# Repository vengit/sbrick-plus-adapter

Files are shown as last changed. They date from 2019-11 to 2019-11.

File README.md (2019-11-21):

# SBrick Plus adapters

This is a repository of code and documentation regarding the SBrick Plus
adapter project.

The material published here is available under the Creative Commons 4.0
International + Noncommercial + NoDerivatives license.

The following material is available:

## Documentation (directory "documentations")

Documentation covers some introduction, description of the physical parts and
some assembly instructions.

## Gerber files (directory "gerbers")

Gerber files can be used to manufacture the printed circuit boards (PCBs).

There are separate PCBs for sensor and motor adapters.

## Firmware code (directory "sbrick-adapter-firmware")

Sensor adapters contain a microcontroller. This microcontroller must be
programmed before use. The source code of the program is provided in the
directory called "sbrick-adapter-firmware".

## Schematic for the electronics (directory "schematic")

Contains schematics for the motor and sensor adapters. The schematic files
can be opened with [gEDA schematic editor](http://www.geda-project.org/).
Also contains bill of materials.

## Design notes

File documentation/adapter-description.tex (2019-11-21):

\documentclass[a4paper,12pt]{article}

\usepackage[utf8]{inputenc}
\usepackage[T1]{fontenc}
\usepackage[english]{babel}
\usepackage{times}
\usepackage{graphicx}

\setlength{\parindent}{0pt}
\setlength{\parskip}{2ex}

\title{SBrick Plus adapter types, parts, assembly steps}

\author{VENGIT Ltd.}

\begin{document}

\maketitle

\pagebreak

\section{Relevant LEGO product lines}

This document contains references to various LEGO product lines. In the
following pages there are descriptions and images of these product lines.

\subsection{LEGO Technic}

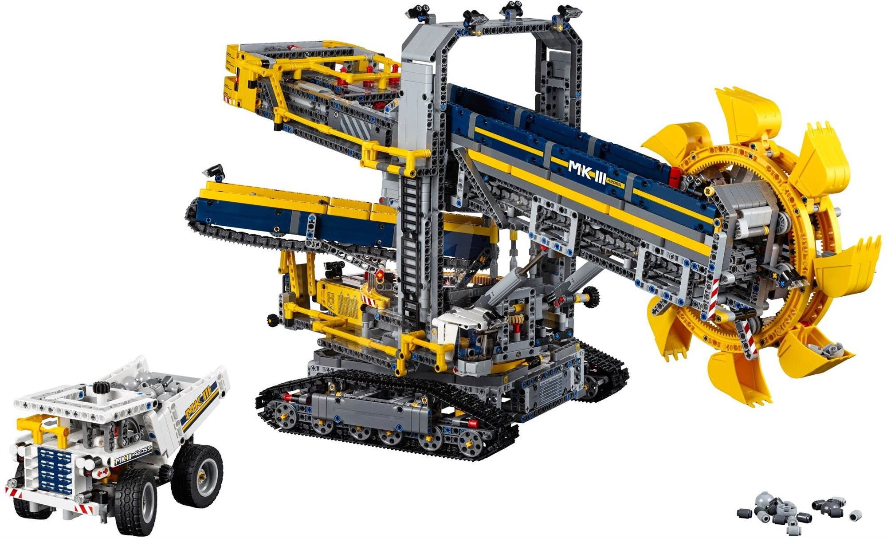
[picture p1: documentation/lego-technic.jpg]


Plastic connecting rods, shafts, pins, gears and similar parts. It's purpose
is to enable building more complex mechanical models than what is possible
with the more traditional "studded" LEGO blocks.

\subsection{LEGO Power Functions}

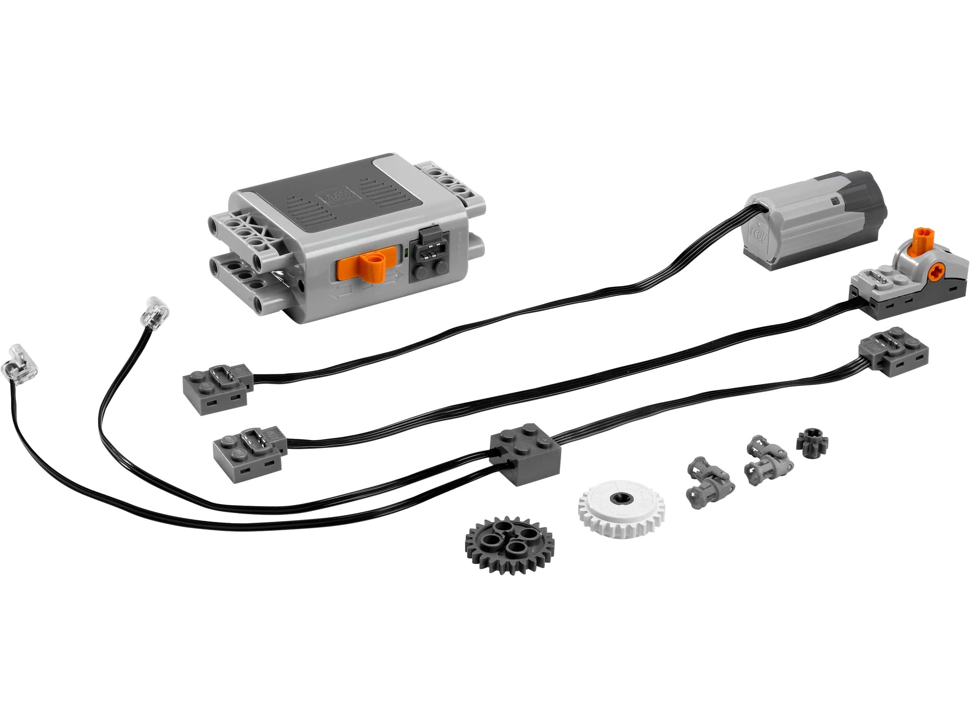
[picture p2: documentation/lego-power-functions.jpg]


Can be used with the LEGO Technic family, available from 2007. Engines, and
other accessories: lighting, battery box, rechargable battery, extension cable,
switch, remote controls. These can be used to turn manually operated Technic
models into battery operated toys.

\subsection{LEGO WeDo}

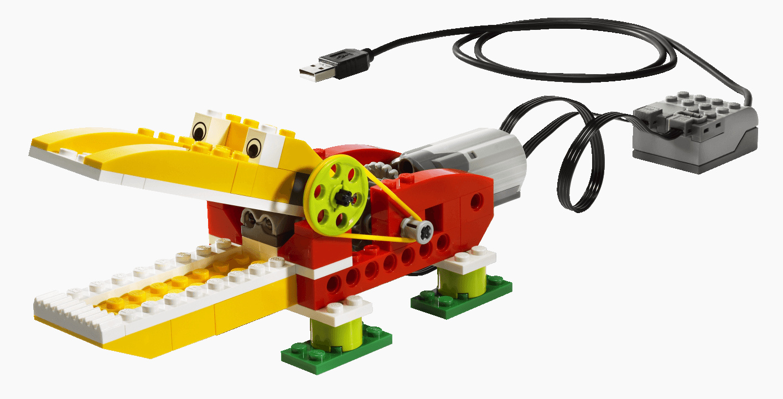
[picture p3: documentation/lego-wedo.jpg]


Central unit with USB connectivity and four connectors. Motor, tilt sensor,
proximity sensor.

\subsection{LEGO WeDo 2.0}

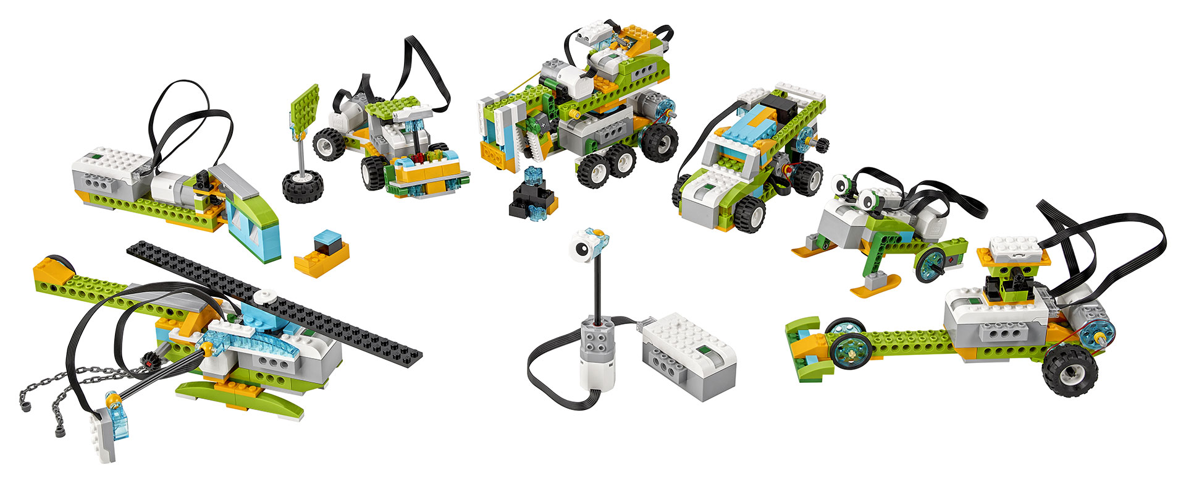
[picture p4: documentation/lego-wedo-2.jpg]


The next version of the WeDo set with different connectors and a smarter,
Bluetooth capable central unit.

\subsection{LEGO Boost}

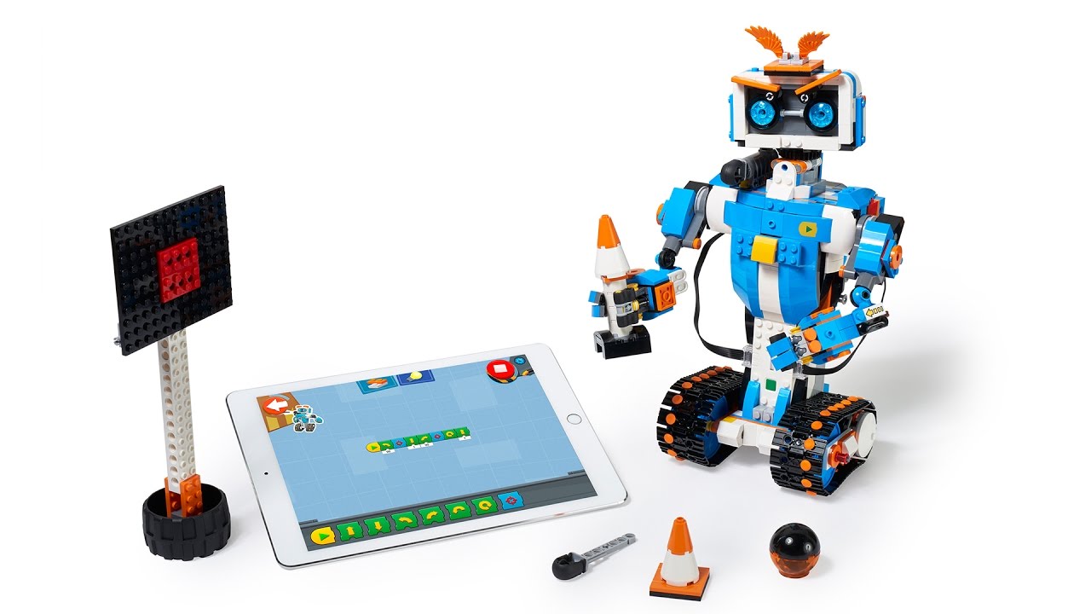
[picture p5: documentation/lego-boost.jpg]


Robotic building set with parts similar to WeDo 2.0, with identical connectors.
While the WeDo line of products are primarily for education purposes, the Boost
line is mainly for play.

\subsection{LEGO MindStorms EV3}

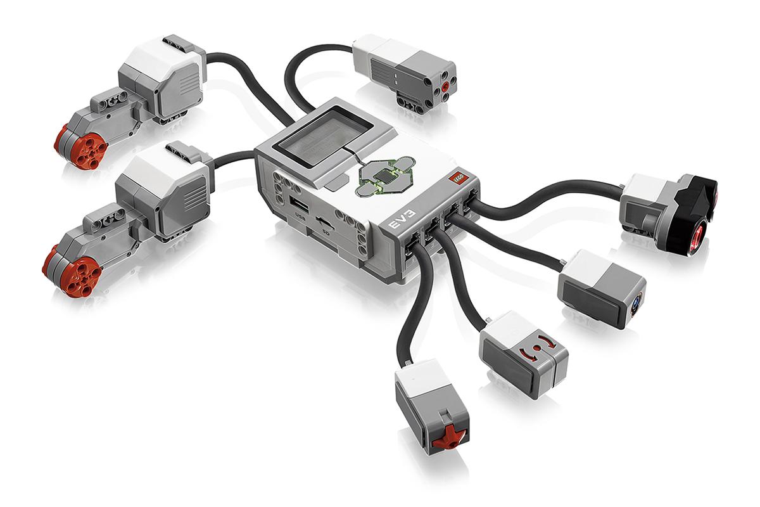
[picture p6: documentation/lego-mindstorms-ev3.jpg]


Robotic building set with central unit, motors, sensors, and cables. The set
uses connectors \emph{similar} to RJ12 (6P6C modular).

\subsection{LEGO MindStorms NXT 1.0 and 2.0}

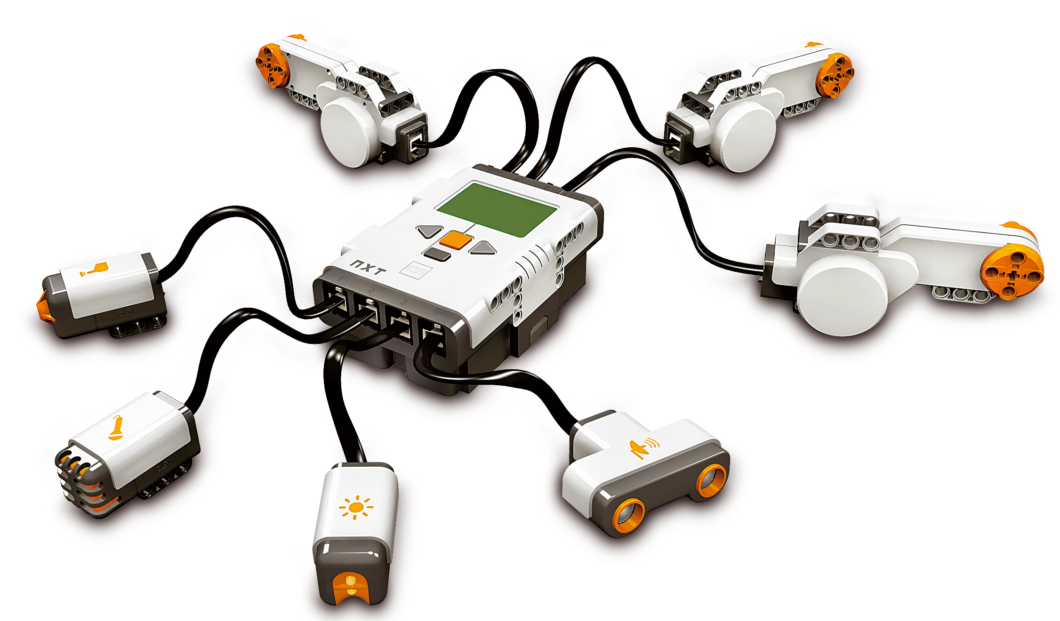
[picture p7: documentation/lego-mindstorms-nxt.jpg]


Robotic building set similar to EV3.

\section{Role and operation the SBrick Plus adapters}

\emph{SBrick} can only be used with Power Functions motors, servos and lights.
Although WeDo sensors can be physically attached to SBrick, they cannot be
used, since SBrick can't read the voltage they output.

\emph{SBrick Plus} can measure voltage, so it can be used with WeDo sensors.

The role of the adapters is to connect certain LEGO EV3/NXT and WeDo2 motors
and sensors physically, electricly and logically.

Although the SBrick can attach to any adapter, it's only useful to attach motor
adapters to it. Accidentally connecting sensor adapters to an SBrick should
never cause damage to the sensor nor to the SBrick.

The motor and sensor adapters are electronically different, so connecting
motors and sensors must be done with different adapters.

The EV3/NXT and WeDo 2 connectors are different, so they also need different
adapters.

\section{Adapter parts}

\subsection{Populated sensor adapter circuit}

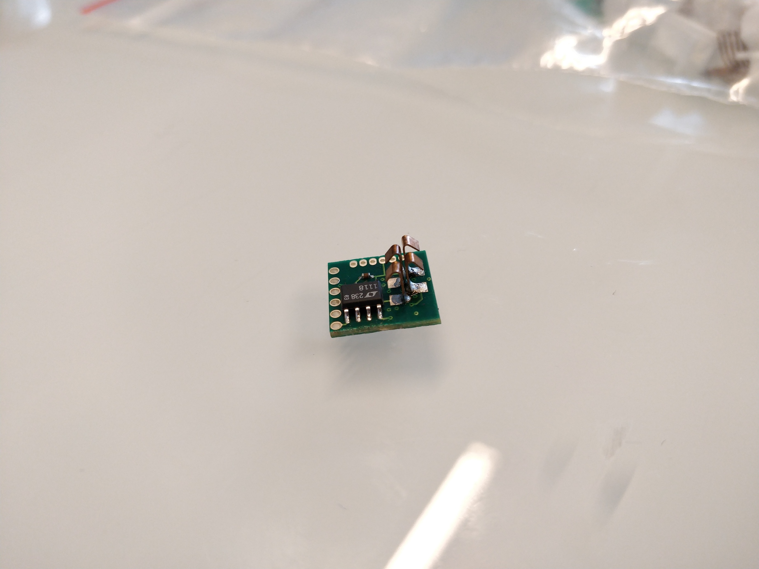
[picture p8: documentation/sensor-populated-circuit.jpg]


\subsection{Populated motor adapter}

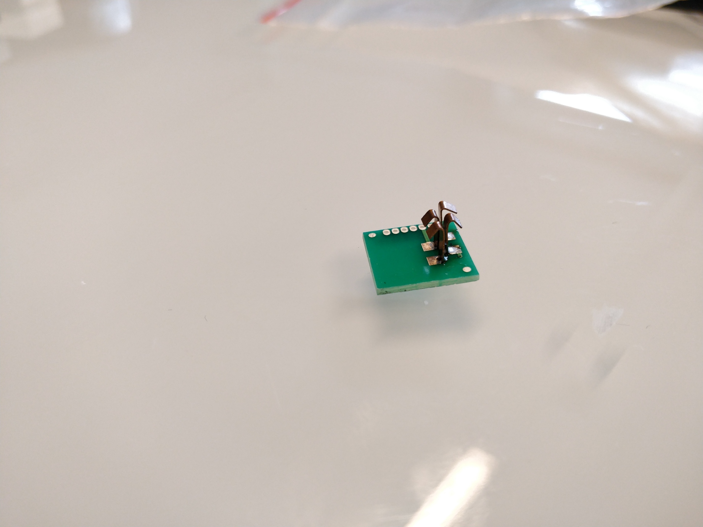
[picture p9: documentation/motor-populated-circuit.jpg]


\subsection{Wedo 2 adapter pins}

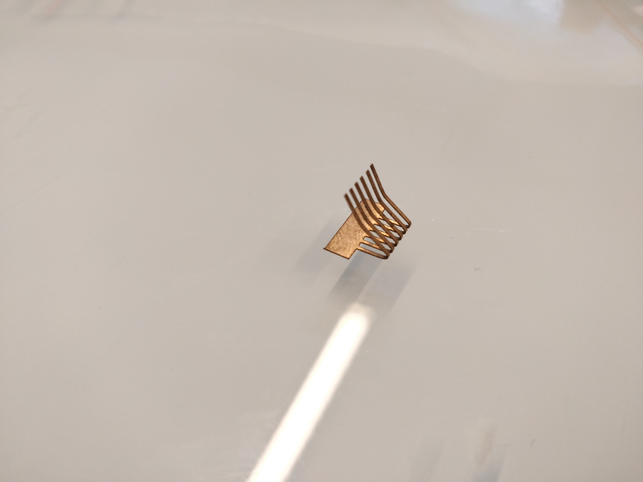
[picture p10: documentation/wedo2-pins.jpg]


\subsection{Power Functions pins}

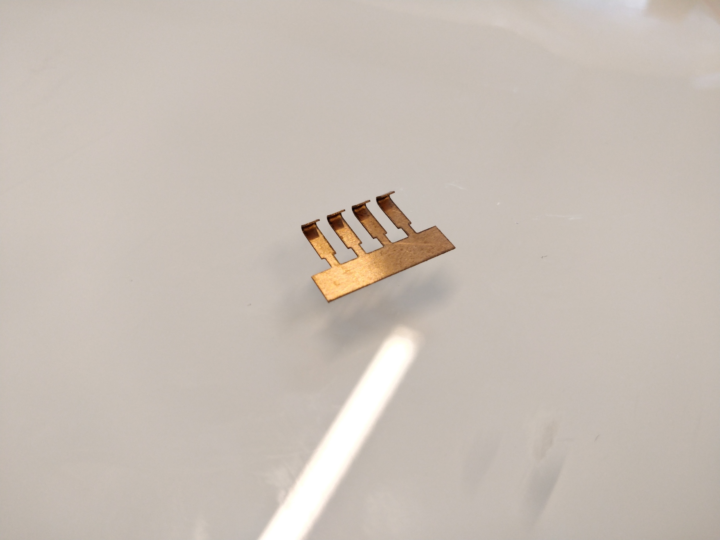
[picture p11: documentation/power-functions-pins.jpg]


\subsection{Wedo 2 motor adapter case insert}

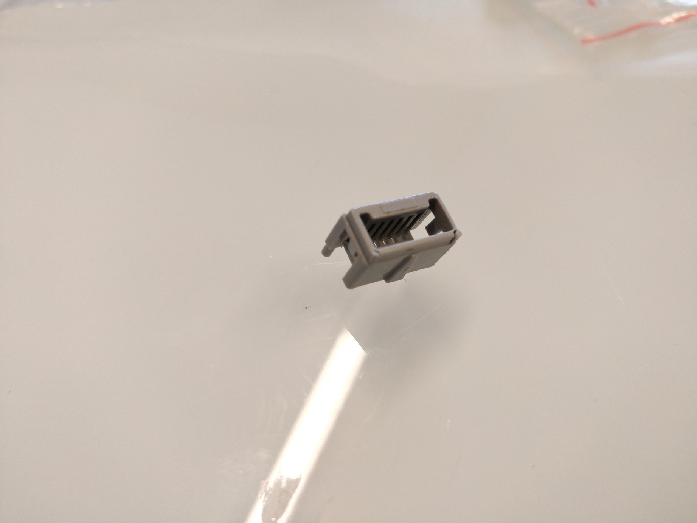
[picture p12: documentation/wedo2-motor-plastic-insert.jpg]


\subsection{EV3 motor adapter case insert}

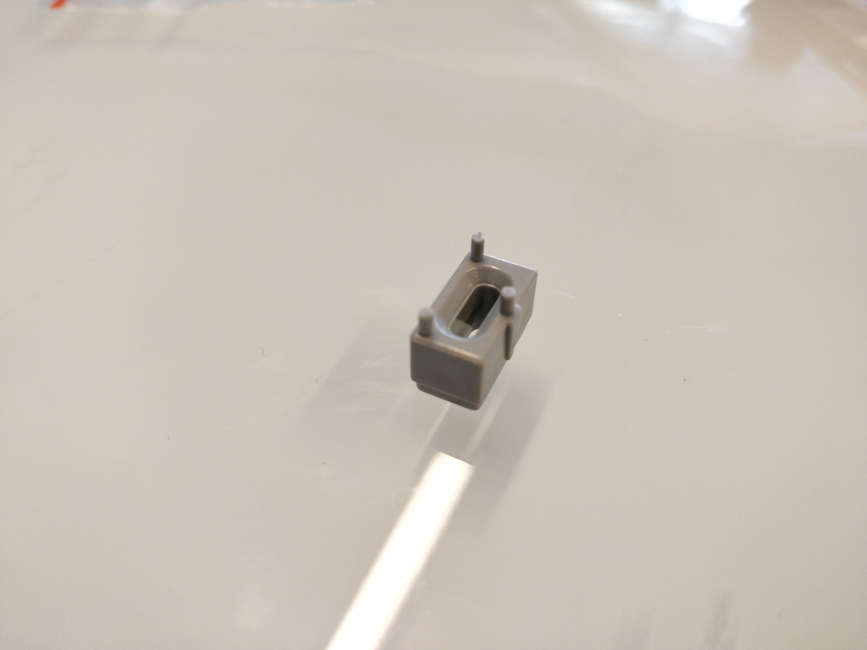
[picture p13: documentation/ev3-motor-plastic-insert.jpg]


\subsection{Motor adapter case top part}

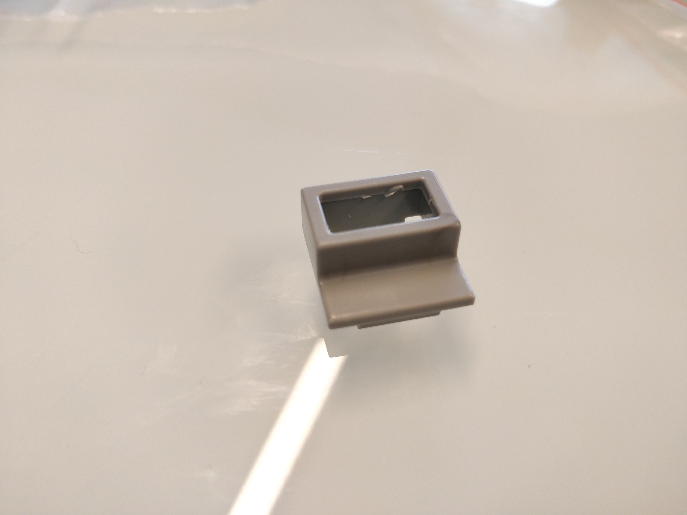
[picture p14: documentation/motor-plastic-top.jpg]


\subsection{Motor adapter case bottom part}

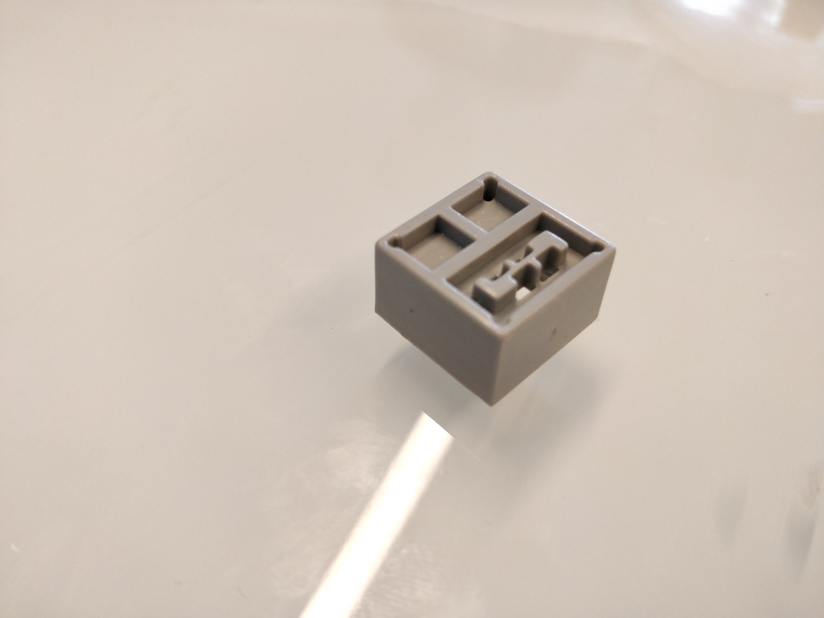
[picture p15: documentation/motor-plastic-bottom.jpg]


\subsection{Sensor adapter case top part}

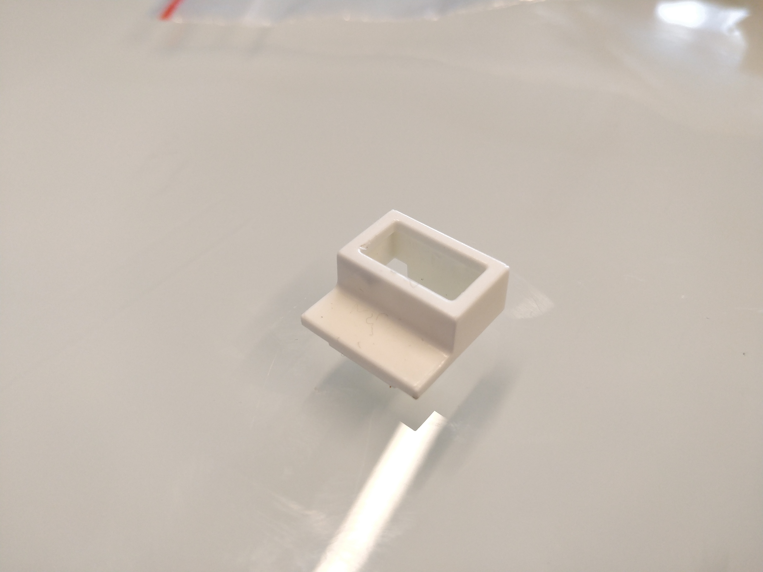
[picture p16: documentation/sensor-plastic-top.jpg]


\subsection{Sensor adapter case bottom part}

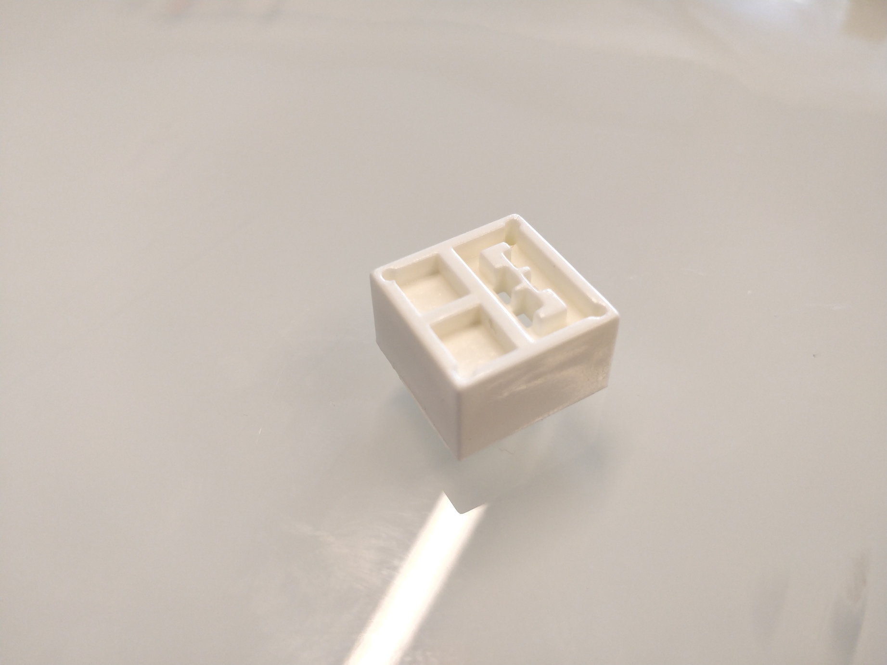
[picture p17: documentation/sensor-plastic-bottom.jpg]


\subsection{EV3 sensor adapter case insert}

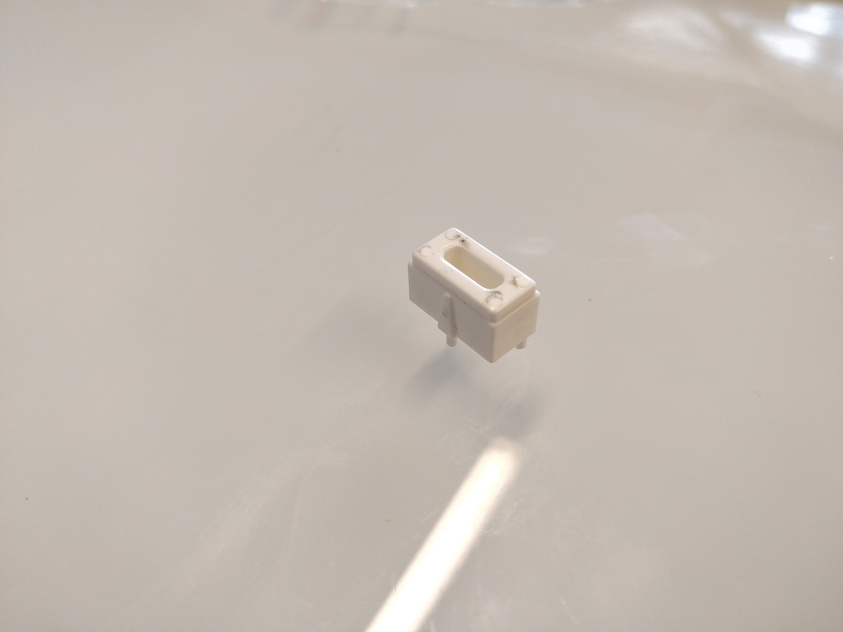
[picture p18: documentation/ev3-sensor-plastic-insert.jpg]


\subsection{Wedo 2 sensor adapter case insert}

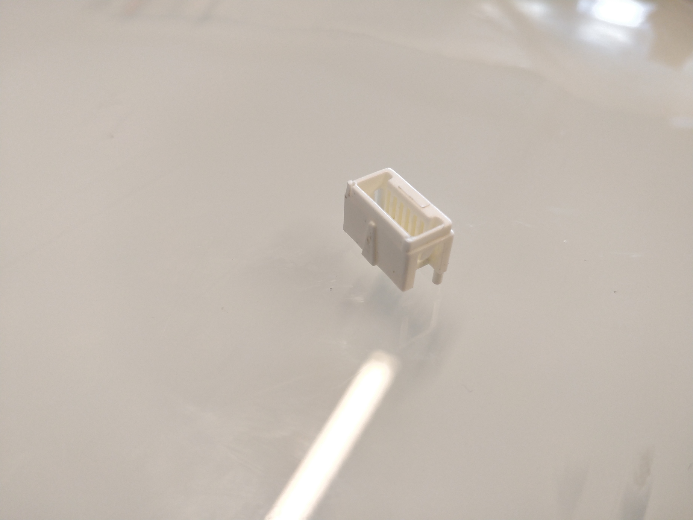
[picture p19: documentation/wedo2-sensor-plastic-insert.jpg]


\subsection{EV3 adapter crimp-on connector}

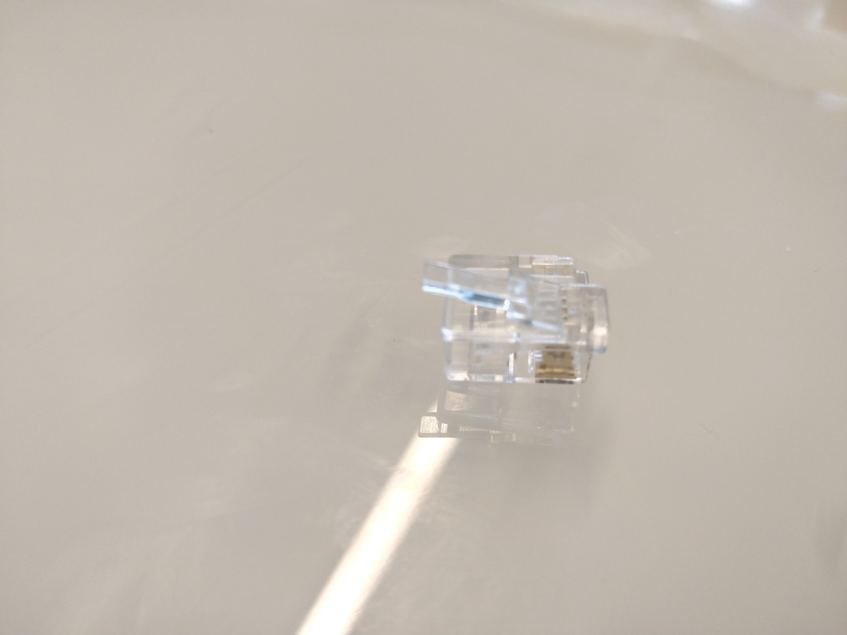
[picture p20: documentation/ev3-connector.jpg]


\subsection{EV3 adapter cable}

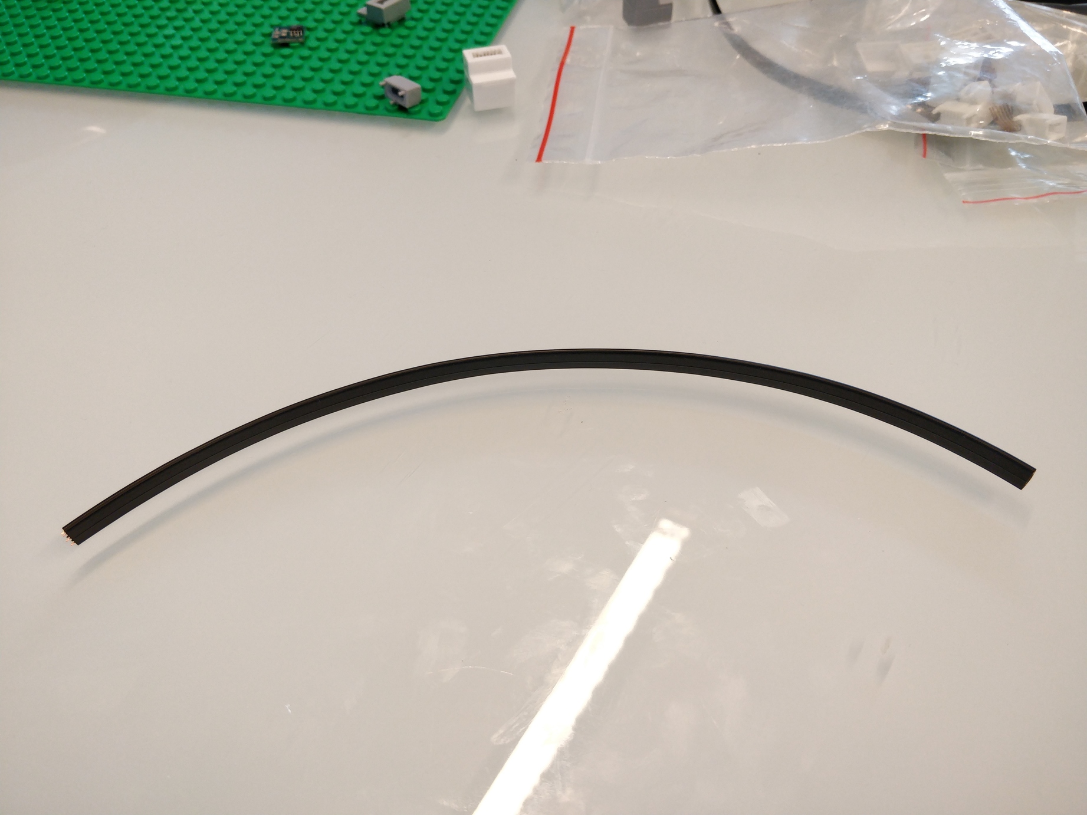
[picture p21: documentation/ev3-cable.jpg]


\subsection{Super glue}

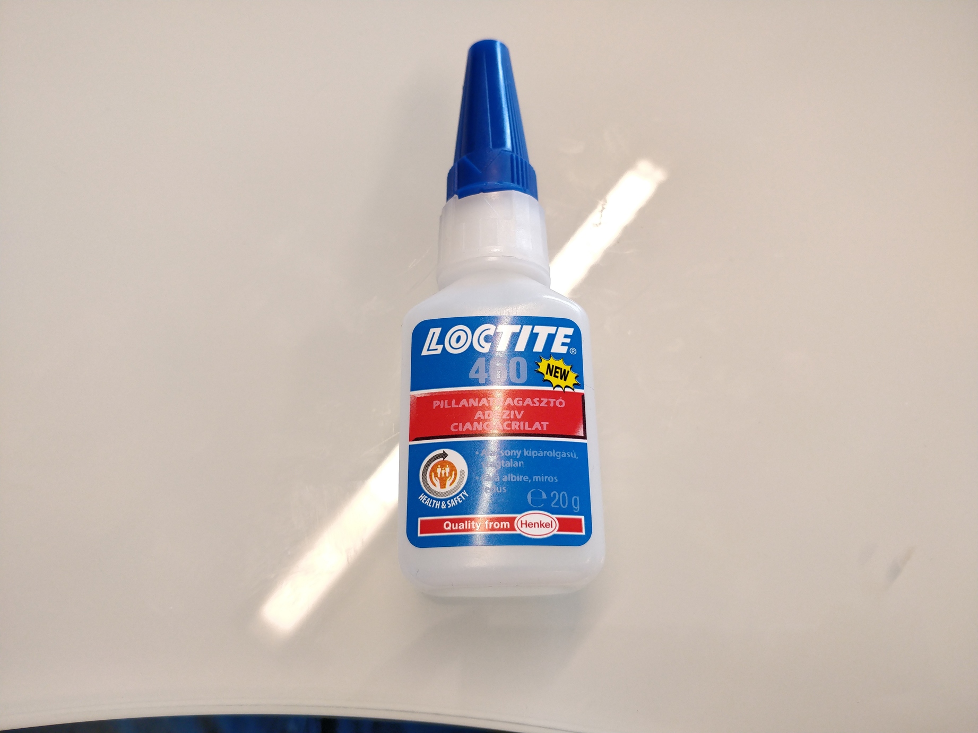
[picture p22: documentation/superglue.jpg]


\subsection{assembled EV3 sensor adapter}

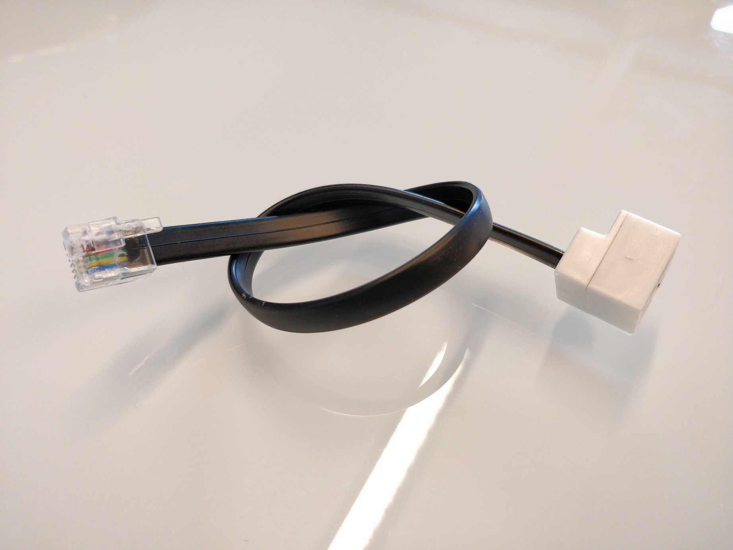
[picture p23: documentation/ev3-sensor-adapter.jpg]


\subsection{Assembled WeDo2 sensor adapter}

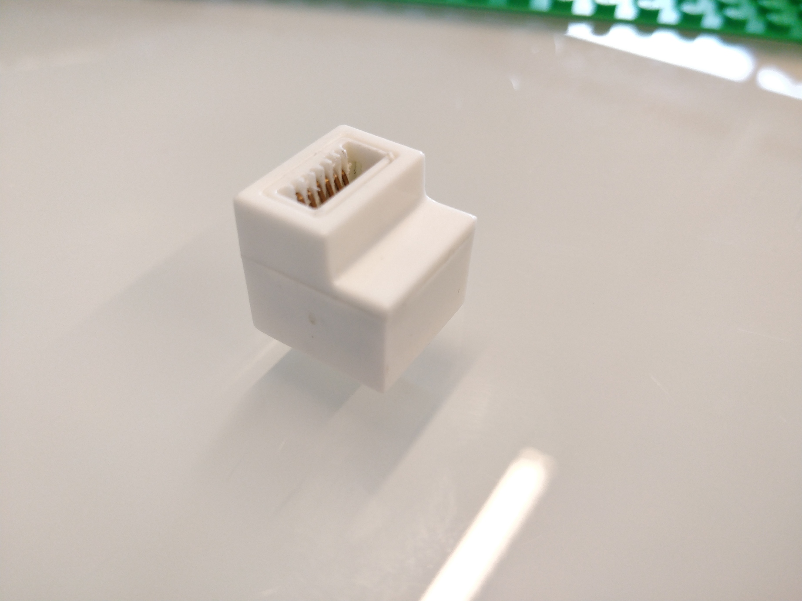
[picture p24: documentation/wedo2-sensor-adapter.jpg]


\subsection{Assembled EV3 motor adapter}



\subsection{Assembled WeDo2 motor adapter}



\section{Programming sensor adapters}

During programming, the ATTiny 841 microcontroller receives the firmware and
executes the calibration code for the built-in RC oscillator.

Programming can be done with Microsoft Windows 7 SP1 or more recent operating
system.

Programming is done by executing a .bat file.

The programming hardware consists of an Atmel Ice USB programmer, a power
supply adapter, a power supply, and connecting cables.

The power supply adapter supplies power for the device during programming.
The different sensor adapter require different power supply adapters. EV3
adapters run on 5 volts, while WeDo2 adapters run on 3.3 volts.

\section{Adapter assembly}

\subsection{WeDo 2 adapters}

\begin{enumerate}
    \item Soldering SMD parts and Power Functions pins.

    \item Programming (in the case of sensor adapters).

    \item Soldering WeDo 2 pins.

    \item Fitting the populated board into the plastic case bottom.

    \item Assembly of the plastic case top half: the appropriate insert must be
    inserted into the top part and fixed with a drop of super glue.

    \item Final step: the bottom and top half must be mated by carefully
    inserting the six pins into their respective slots. The two halves must be
    pressed together firmly.
\end{enumerate}

\subsection{EV3 adapters}

\begin{enumerate}
    \item PCB soldering.

    \item Programming (in case of sensor adapters).

    \item Preparation of the cable: both ends of the six-core cable must be
    stripped. All of the conductors must be stripped at one end, only the
    outer jacket have to be stripped at the other end.

    \item Crimping: the connector must be crimped with the appropriate tool.
    Use the end where the individual conductors \emph{are not} stripped.

    \item Assembling the top half: the insert and the plastic case top must
    be mated and secured with a drop of glue.

    \item The top half case must be slided onto the cable.

    \item The stripped conductors must be soldered onto the PCB.

    \item The PCB must be pressed into the plastic case bottom. The plastic
    case top and bottom halves must be pressed together firmly.

    \item The cable jacket and the insert must be glued together.
\end{enumerate}

\end{document}

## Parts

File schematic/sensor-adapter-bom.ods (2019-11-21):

# | Qty | Reference | Part name | Value | Manufacture | Description
1 | 1 | R1 | Resistor | 10k |  | 0402
2 | 1 | R2 | Resistor | 220R |  | 0402
3 | 1 | R3 | Resistor | 10k |  | 0402
4 | 1 | R4 | Resistor | 100k |  | 0402
5 | 1 | R5 | Resistor | 150K / 196k | 3,3V / 5V | 0402
6 | 1 | R6 | Resistor | 90,9k / 64,9k | 3,3V / 5V | 0402
7 | 2 | C1,2 | Capacitor | 470n |  | 0402
8 | 2 | D1,2 | Schottky diode | PMEG3002AEB | Nexperia | SOD523
9 | 1 | U1 | Voltage regulator IC | LT1118 | Analog D. (Linear T.) | SOT223
10 | 1 | U2 | Microcontroller IC | ATTiny841 | Microchip (Atmel) | 20M2

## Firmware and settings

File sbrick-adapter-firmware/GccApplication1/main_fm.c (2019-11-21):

#include <avr/eeprom.h>
#include <avr/io.h>
#include <avr/interrupt.h>
#include <avr/sleep.h>
#include <avr/fuse.h>
#include <avr/lock.h>
#include <stdio.h>
#include <stdlib.h>
#include "capture.h"
#include "ser.h"
#include "ser1.h"
#include "pwm.h"
#include "timer.h"
#include "adc.h"
#include "main_fm.h"
#include "main_uart.h"

#include <util/delay.h>

FUSES =
{
    /* 8MHz internal RC oscillator, no clock output, no clock divison */
    .low = 0xE2,

    /* BOD @ 2.7V, serial programming enabled*/
    .high = 0xDD,

    /* 32KHz ULPOSC (not used), BOD active on all power levels */
    .extended = 0xF5
};

/* No further reading or writing */
LOCKBITS = LB_MODE_3;

/* F_CPU/1024/100 = 81 */
#define TIMER_10MS 81

/* F_CPU/1024/100 = 2.025 */
#define TIMER_025MS 2

/* Atmel ICE calibration frequency on MOSI pin */
#define ISP_FREQ 32100.0

/* Measure this much caluibration clock cycles */
#define CAL_CLOCK_TICKS 100.0

/* With perfect calibration we should count this many clock ticks */
#define TARGET_TICKS (F_CPU/ISP_FREQ*CAL_CLOCK_TICKS)

/* How many times check the MOSI pin for calibration signal.
 * Should be a 100ms-ish amount. A loop has a 5us wait. */
#define MAX_WAIT_FOR_CALIBRATION 20000

/* MOSI, also the calibration frequency reference pin */
#define MOSI_PIN PA6

/* MISO, signals back to the programmer during calibration */
#define MISO_PIN PA5

/* Save calibration info here */
#define EEPROM_CALIBRATION_ADDRESS 0x00

enum main_mode {INIT, INIT_VERIFY, START_OPERATING, OPERATING};

typedef enum main_mode main_mode_t;

main_mode_t mode=INIT;

uint8_t sub_mode=EV3TOUCH_SM;

extern uint16_t p_period;
extern uint16_t p_duty_raw;

/* Returns 1 if the parameters mean we're being initialized */
uint8_t init_freq(uint16_t p, uint8_t d)
{
    if ((p > (INIT_F-DELTA_F)) && (p < (INIT_F+DELTA_F))) {
        if (d>1 && d<254) {
            return 1;
        }
    }
    return 0;
}

uint8_t op_freq(uint16_t p, uint8_t d)
{
    if ((p > (OP_F-DELTA_FH)) && (p < (OP_F+DELTA_FH))) {
            return 1;
    }
    return 0;
}

uint8_t get_submode(uint8_t d)
{
    if ((d<R_MIN) || (d>R_MAX)) {
        return 255;
    } 
    return (d-R_MIN)/R_LANE;
    
}

void debug_flag_init()
{    
        DDRB |= _BV(DDB2);
}
    
void debug_flag_set(uint8_t val)
{
    if (val) {
        PORTB |= _BV(PB2);
    } else {
        PORTB &= ~(_BV(PB2)); // SET 0
    }
}

uint8_t scale(uint8_t val)
{
    uint16_t raw=val;
    return (uint8_t)(raw*8/10+R_MIN);
}

/* Measure the current ticks/calibration cycle
 * and return the difference from the ideal
 */
float tick_difference()
{
    uint8_t high_count = 0;

    /* start counter 0 to count clock ticks */
    TCNT0 = 0;
    TCCR0B = _BV(CS00);

    for (int i = 0; i < CAL_CLOCK_TICKS; i++) {
        /* check for overflow */
        if (TIFR0 & _BV(TOV0)) { TIFR0 |= _BV(TOV0); high_count++; }
        /* wait for rising edge */
        loop_until_bit_is_set(PINA, MOSI_PIN);
        /* check for overflow */
        if (TIFR0 & _BV(TOV0)) { TIFR0 |= _BV(TOV0); high_count++; }
        /* wait for falling edge */
        loop_until_bit_is_clear(PINA, MOSI_PIN);
    }

    /* stop counter */
    TCCR0B &= ~_BV(CS00);

    /* check for overflow */
    if (TIFR0 & _BV(TOV0)) { TIFR0 |= _BV(TOV0); high_count++; }

    /* subtract a few ticks because it takes a few instructions to respond */
    float ticks = ((((uint16_t)high_count)<<8 ) | TCNT0) - 2;

    return ticks - TARGET_TICKS;
}

static FILE mystdout = FDEV_SETUP_STREAM(ser1_putchar, NULL, _FDEV_SETUP_WRITE);

/* Measure a ~32 KHz reference signal on MOSI
 * and adjust the OSCCAL0 register with
 * gradient descent */
void calibrate()
{
    /* This is the best distance from TARGET_TICKS. Set it to a large number. */
    float td_best = UINT16_MAX;

    /* Stores the most precise OSCCAL0 value (for which td_best was measured)
     * Start our setup from the factory value and slowly inch towards the optimal value. */
    uint8_t osccal_best = OSCCAL0;

    for(;;) {
        /* Measure how far we are from TARGET_TICKS */
        float td = tick_difference();

        if (abs(td) < td_best) {
            /* This is better than last time */
            td_best = abs(td);
            osccal_best = OSCCAL0;
        } else {
            /* We're not progressing, quit calibration */
            OSCCAL0 = osccal_best;
            break;
        }

        if (td > 0) {
            /* Too many ticks, clock runs too fast */
            if (OSCCAL0 == 0) {
                break; /* Hit the wall */
            }
            /* Set clock and wait a little for the clock to stabilize.
             * The clock is not stable yet, this is not precise. */
            OSCCAL0 -= 1;
            _delay_us(100);
        } else if (td < 0) {
            /* Too few ticks, clock runs too slow */
            if (OSCCAL0 == 255) {
                break; /* Hit the wall */
            }
            /* Set clock and wait a little for the clock to stabilize.
             * The clock is not stable yet, this is not precise. */
            OSCCAL0 += 1;
            _delay_us(100);
        } else {
            /* When the ticks are just right */
            break;
        }
    }

    /* store fresh, calibrated OSCCAL0 value in eeprom */
    eeprom_busy_wait();
    eeprom_update_byte(0x00, OSCCAL0);
    eeprom_busy_wait();

    /* toggle MISO line 8 times to signal success */
    for (int i = 0; i < 8; i++) {
        /* wait for falling edge */
        loop_until_bit_is_clear(PINA, MOSI_PIN);
        /* toggle MISO */
        PINA |= _BV(MISO_PIN);
        /* wait for rising edge */
        loop_until_bit_is_set(PINA, MOSI_PIN);
    }
}

/* Load the RC oscillator calibration value from the
 * configured EEPROM location. */
void load_calibration()
{
    uint8_t cal = eeprom_read_byte(EEPROM_CALIBRATION_ADDRESS);
    if (cal == 0xff) {
        /* The EEPROM looks like it's not programmed. Don't change OSCCAL0. */
        return;
    }
    OSCCAL0 = cal;
}

int calibration_clock_present()
{
    uint32_t i = 0;

    while (bit_is_clear(PINA, MOSI_PIN)) {
        _delay_us(5); /* Clock is uncalibrated might take 2-10us */
       i++;
       if (i > MAX_WAIT_FOR_CALIBRATION) {
           return 0;
       }
    }

    while (bit_is_set(PINA, MOSI_PIN)) {
        _delay_us(5); /* Clock is uncalibrated might take 2-10us */
        i++;
       if (i > MAX_WAIT_FOR_CALIBRATION) {
           return 0;
       }
    }

    return 1;
}

/**
 * Entry point
 */
int main(void)
{
    /* Make printf() work */
    stdout = &mystdout;

    /* set MISO as output */
    DDRA |= _BV(MISO_PIN);

    /* set MOSI as input */
    DDRA &= ~_BV(MOSI_PIN);

    /* enable pull-up resistor on MOSI */
    PUEA |= _BV(MOSI_PIN);

    /* set MISO high to signal the programmer that we're ready */
    PORTA |= _BV(MISO_PIN);

    /* Check if we're receiving a clibration clock signal */
    if (calibration_clock_present()) {
        /* No, there must be a calibration signal present */
        calibrate();
    } else {
        /* Yes, there was a timeout, use previously saved or factory value */
        load_calibration();
    }

    /* Continue with the calibrated, loaded, or factory OSCCAL0 */

    ser_begin(2400);
    //ser_begin(115200);
    //for (;;) ser_write(0b10101010);
    ser_begin1(115200);

    capture_init();
    timer_init();
    adc_init();
    pwm_init();
    debug_flag_init();
    pwm_set(0);
    timer_set(0);
    debug_flag_set(0);
    sei();

    uint8_t error_cnt=0;
    uint8_t error_state=0;
    uint8_t error_len=0;

    uint8_t tmp=0;
    uint16_t start_time=0;

    /* calibration check */
    // pwm_set(127); for(;;);

    /********DEBUG SETTINGS ***************/
    // mode = OPERATING;
    // pwm_set(R_MIN);
    // start_time = timer_get();
    // sub_mode = UARTMODE0_SM;
    //***************************************
    debug_flag_set(0);

    for (;;)
    {
        /*
         * Fetch the latest reading and display it on the LEDs.
         */        
        uint16_t p=p_period;
        uint8_t d=get_duty(p_period, p_duty_raw);

        /*if (error_len>1) {
            debug_flag_set(1);    
        } else {
            debug_flag_set(0);
        }*/
        //DEBUG: ser_write1(p>>8);
        //DEBUG: ser_write1(p&0xff);
        switch (mode) {
        case INIT:
            if (init_freq(p, d)) {
                init_main_uart();
                ser_begin(2400);
                mode=INIT_VERIFY;
                sub_mode=get_submode(d);
            }
            start_time=timer_get();
            pwm_set(0);
            break;
        case INIT_VERIFY:
            //debug_flag_set(0);
            if (init_freq(p, d) && sub_mode==get_submode(d)) {
                if ((timer_get()-start_time)>(TIMER_10MS*15)) {
                    start_time=timer_get();
                    mode=START_OPERATING;
                    pwm_set(R_MIN);
                        
                }
            } else {
                mode=INIT;
                pwm_set(0);
            };
            break;
        case START_OPERATING:
            if ((timer_get()-start_time)>TIMER_10MS*50) {
                if (op_freq(p, d)) {
                    mode=OPERATING;
                    start_time=timer_get();
                } else {
                    mode=INIT;
                }
            }
            break;
        case OPERATING:
            if (timer_get()-start_time>TIMER_10MS*10) {
                if (error_cnt>40) {
                    mode=INIT;
                    pwm_set(0);
                    //DEBUG ser_write1('I');
                }
                start_time=timer_get();
                error_cnt=0;
                error_state=0;
            }
            if (!op_freq(p, d)) {
                if (error_state==0) {
                    error_state=1;
                    error_len=1;
                } else {
                    error_len++;
                }
            } else {
                if (error_state==1) {
                    error_state=0;
                    if (error_len>1) {
                        error_cnt++;
                        error_len=0;
                    }
                }
            }
            switch(sub_mode) {
            case EV3TOUCH_SM:
                if ((EV3PIN6 & _BV(EV3P6))==_BV(EV3P6)) {
                    tmp=R_MAX;
                } else {
                    tmp=R_MIN;
                }
                pwm_set(tmp);
                break;
            case NXTTOUCH_SM:
                tmp=get_adc();
                if (tmp<128) {
                    pwm_set(R_MAX);
                } else {
                    pwm_set(R_MIN);
                }
                break;
            case NXTLIGHT_SM:
                tmp=scale(get_adc());
                pwm_set(tmp);
                break;
            case UARTMODE0_SM:
            case UARTMODE1_SM:
            case UARTMODE2_SM:
            case UARTMODE3_VM:
            case UARTMODE4_VM:
            case UARTMODE5_VM:
            case UARTMODE6_VM:
                main_uart();
                break;
            }
            break;
        }
    }
}

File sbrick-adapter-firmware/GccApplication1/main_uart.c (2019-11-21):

#include <stdio.h>
#include <stdlib.h>
#include <avr/io.h>
#include <avr/interrupt.h>
#include <inttypes.h>
#include "main_uart.h"
#include "ev3_utils.h"
#include "ev3.h"
#include "ser.h"
//DEBUG #include "ser1.h" 
#include "pwm.h"
#include "timer.h"
#include "main_fm.h"
#include "uart_calc.h"

state_type ms=READY; // state of the UART processing
sm_state msm; // sub state of the UART processing step
sensor_type sensor; // sensor type record
uint8_t databuf[BUFFSIZE]; // stores input data from the sensor

uint8_t cmdbuf[7]; // output command buff for mode change

#include "ev3_inline_mem.h"

uint8_t read_serial_single()
{
    return ser_read();
}

uint8_t write_serial_single(uint8_t outc)
{
    return ser_write(outc);
}

uint8_t write_serial(uint8_t outc[], uint8_t size)
{
    uint8_t res = 0;
    for(uint8_t i = 0; i<size; i++) {
        res=ser_write(outc[i]);
        if (res != 1)
        break;
    }
    return res;
}

uint8_t ser_open()
{
    ser_begin(2400);
    return 0;
}

uint8_t ser_reopen(uint32_t rate)
{
    ser_changebaud(rate);
    return 0;
}

// time base is 128 us
#define TIMER_100MS 780 
#define TIMER_7_2MS 56

uint8_t type_flag=0, mode_flag=0, speed_flag=0; // flags of header infos; all have to be read to start receiving data
uint32_t baud=0; // baud of the communication
uint8_t in_data=0; // 

//int res=0;
uint16_t sensor_read_val=0;
uint16_t timer_startu=0;
uint8_t valid_data=0;
uint8_t first_tick=1;
uint8_t mode_tick=0;
uint8_t data_err_counter=0;
extern uint8_t sub_mode;
uint8_t buff_count=0;

void init_main_uart()
{
    type_flag=0, mode_flag=0, speed_flag=0;
    ms=READY;
    init_sm_state();
    msm.i_counter=0;
    sensor_read_val=0;
    valid_data=0;
    first_tick=1;
    mode_tick=0;
}

void reset_communication()
{
    ser_reopen(2400);
    type_flag=0, mode_flag=0, speed_flag=0;
    valid_data=0;
    first_tick=1;
    mode_tick=0;
    init_sm_state();
    ms=READY;
}

void main_uart()
{
    if (ms==DATASYNC || ms==DATAPREP || ms==DATAREADY || ms==DATA) {
        if (first_tick) {
            if((timer_get()-timer_startu)>TIMER_7_2MS) {  // ~7,2 ms
                write_serial_single(NACK);
                timer_startu=timer_get();
                first_tick=0;
                if (sub_mode!=UARTMODE0_SM || UARTMODE3_VM) {
                    mode_tick=1;
                }
            } 
        } else if (mode_tick) {
            if(timer_get()-timer_startu>TIMER_100MS/10) {
                    if (sub_mode==UARTMODE1_SM || sub_mode==UARTMODE4_VM  || sub_mode==UARTMODE5_VM || sub_mode==UARTMODE6_VM) {
                        set_mode(cmdbuf, 1);
                        write_serial(cmdbuf, 3);
                        write_serial(cmdbuf, 3);
                        write_serial(cmdbuf, 3);
                    } else if (sub_mode==UARTMODE2_SM) {
                        set_mode(cmdbuf, 2);
                        write_serial(cmdbuf, 3);
                        write_serial(cmdbuf, 3);
                        write_serial(cmdbuf, 3);
                    }
                    mode_tick=0;
            }
        } else {
            if(timer_get()-timer_startu>TIMER_100MS) {  // ~100 ms
                if (valid_data==1) {
                    write_serial_single(NACK);
                    timer_startu=timer_get();
                    valid_data=0;
                    data_err_counter=0;
					//DEBUG ser_write1('A');
                } else {
                    timer_startu=timer_get();
                    reset_communication();
					//DEBUG ser_write1('R');
                }
            }
        }
    }
    //Handle serial stuff
    buff_count = ser_available();
    if (buff_count) {
        //DEBUG ser_write1('T');
        in_data=read_serial_single();
        if (ms==DATASYNC || ms==DATAPREP || ms==DATAREADY || ms==DATA) {
            if ((buff_count>10) &&(ms == DATASYNC || ms == DATAPREP || ms == DATAREADY) && get_type(in_data) == TYPE_DATA) {
                int dlen=get_length(in_data);
                for (int i=0; i<=dlen; i++) {
                    read_serial_single();
                }
                in_data=read_serial_single();
                //DEBUG ser_write1('D');
            }
            process_content(in_data);
            if (ms==DATAREADY) {
                valid_data=1;
                sensor_read_val=get_sensor_data(databuf);
                pwm_set(scale(sensor_read_val));
            } else if (ms==DATASYNC) {
                //DEBUG ser_write1('Y');
                //data valid flag set after nack signal in timing loop
            } else if (ms==STOP) {
                //DEBUG ser_write1('S');
                if(data_err_counter<5) {
                    ms=DATAPREP;
                } 
            }
        } else {
            process_header(in_data);
            if (ms == TYPE) {
                    type_flag=1;
            } else if (ms == SPEED) {
                if (speed_flag==0) {
                    set_speed(cmdbuf, 115200);
                    write_serial(cmdbuf, 6);
                    speed_flag=1;
                }
            } else if (ms == MODE){
                mode_flag=1;
            } else if (ms == DATAPREP) {
                if (type_flag && speed_flag) {
                    write_serial_single(ACK);
                    ser_flush();

                    _delay_ms(5);
                    baud=sensor.s_speed;

                    ser_reopen(baud);
                    _delay_ms(1);
                    if (ser_available()) {
                        read_serial_single();
                    }
                    first_tick=1;
                    timer_startu=timer_get();
                } else {
                    type_flag = speed_flag = mode_flag = 0;
                    ms = READY;
                    init_sm_state();
                }
            }
            if (ms == STOP) {
                reset_communication();
            }
        }
    }
}
